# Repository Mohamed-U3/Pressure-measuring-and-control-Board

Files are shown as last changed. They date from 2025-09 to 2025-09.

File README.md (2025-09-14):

# ESP‑12 Pressure Control Circuit

A modular ESP‑12E (ESP8266) hardware design for pressure sensing, load driving, and safe power management with battery charging and automatic source switchover.

<div align="center">
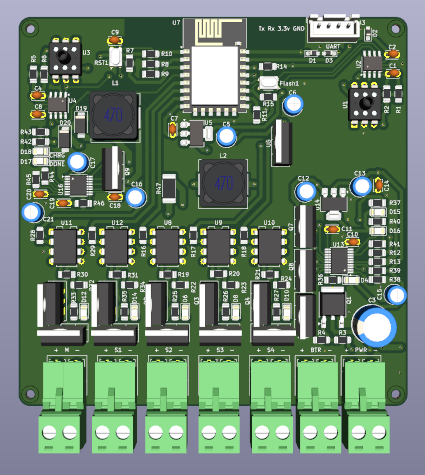
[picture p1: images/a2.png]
  
</div>

<div align="center">
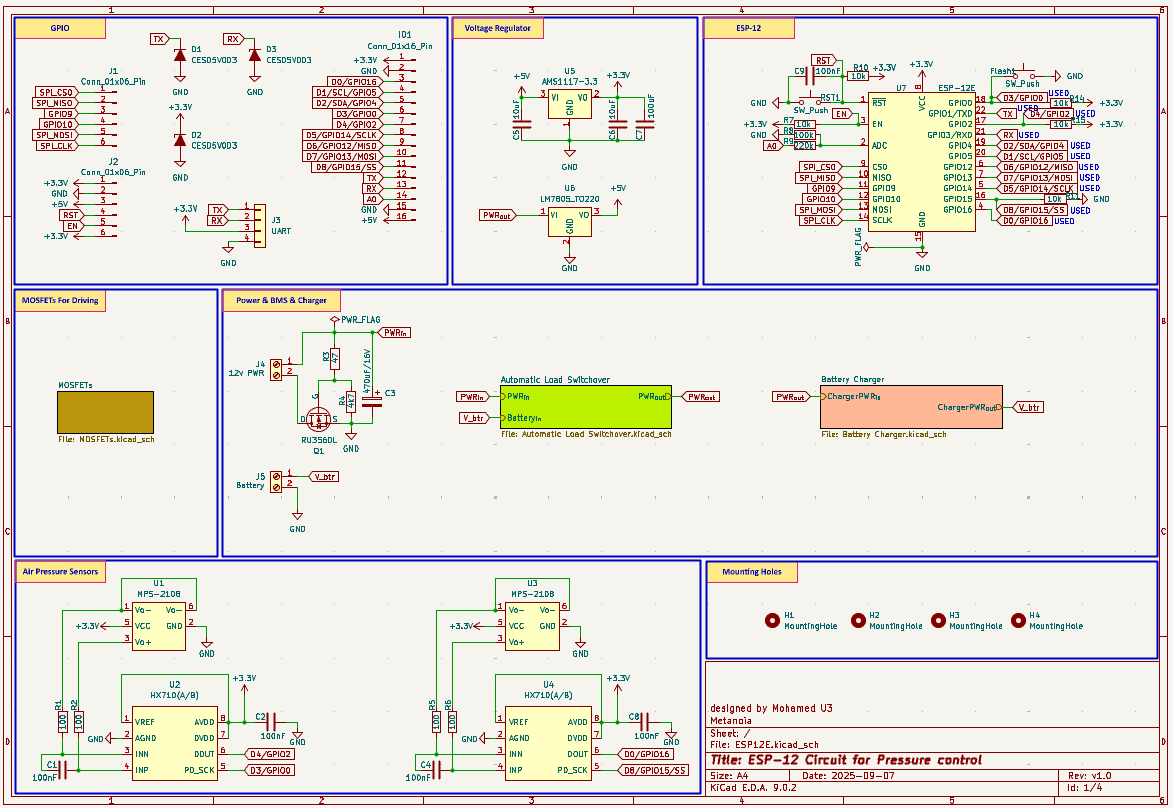
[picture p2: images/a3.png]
  
</div>

## Overview

This repository contains KiCad 9.0.2 schematics for a pressure‑control system built around an ESP‑12E module, dual precision pressure measurement channels, high‑side battery/adapter power path control, and isolated MOSFET drivers for solenoids and a motor.
The design includes an onboard CN3703 Li‑ion charger, AMS1117‑3.3/LM7805 regulators, TLP250 gate drivers, and IRF540N power MOSFETs with Schottky flyback protection, organized across four hierarchical sheets.

## Schematic set

- ESP‑12 top‑level: ESP‑12E module, boot/EN/RST conditioning, ESD protection, sensor ADCs, and header breakout.
- MOSFETs: Four opto‑isolated TLP250 driver channels feeding IRF540N MOSFETs for Sol_1…Sol_4 and Motor outputs with MBR745 freewheel diodes and LED indicators.
- Automatic Load Switchover: LTC2952 power management, dual 2SJ174 P‑MOSFET path control, and local 3.3 V/5 V regulation for state control and status.
- Battery Charger: CN3703 Li‑ion charger with SS36 rectifiers, 22 µH power inductors, 0.1 Ω sense, and charge/done LED indicators.

## Files and structure

- ESP12E.kicad_sch: Top‑level ESP‑12 sheet with sensors, regulators, ESD, UART, and I/O header.
- MOSFETs.kicad_sch: Isolated drivers, MOSFET power stages, connectors for solenoids and motor.
- Automatic Load Switchover.kicad_sch: LTC2952 control, P‑channel power multiplexing, timing/configuration network.
- Battery Charger.kicad_sch: CN3703 charger stage with power path elements and indicators.

## Power architecture

- Input power is provided via a 12 V PWR connector with bulk filtering (e.g., 470 µF/16 V C3) feeding a 5 V LM7805 and a 3.3 V AMS1117 rail, duplicated where needed on control sheets.
- Automatic source switchover uses LTC2952 to supervise ON/OFF timing, power‑fail, watchdog, and gate‑drive outputs for back‑to‑back 2SJ174 P‑MOSFETs controlling PWR_in/PWR_out and Battery_in.
- The CN3703 charger implements Li‑ion charging with SS36 diodes, 22 µH inductors, 0.1 Ω current sense, and CHRG/DONE LED status, feeding the battery power domain.

## Sensing and ADC

- Two HX710(A/B) precision ADC channels interface differential pressure sensors labeled MPS‑2108, each with Vo+/Vo−, VCC, and local decoupling.
- Each ADC section provides AVDD/DVDD partitioning, PD_SCK/DOUT digital lines to the ESP‑12E, and VREF/AGND nodes for stable measurement.

## Microcontroller core

- ESP‑12E (ESP8266) module exposes GPIO0–GPIO16, UART TX/RX, SPI, ADC (A0), EN, and RST, with pull networks for proper boot mode and reset behavior.
- ESD protection diodes (CESD5V0D3) are placed on sensitive I/O and rails including UART, reset, and 3.3 V nodes to improve robustness.

## Isolated drivers and loads

- Four TLP250 opto‑gate drivers provide isolation between the ESP‑12 logic domain and the IRF540N power stages, each with dedicated gate resistors and LED activity indicators.
- Outputs are presented on headers as Sol_1, Sol_2, Sol_3, Sol_4, and Motor, each clamped by MBR745 Schottky diodes for inductive flyback protection.

## Connectors

- J4 12v PWR: main DC input for the regulator stages and system rails.
- J6–J10: load connectors labeled Sol_1…Sol_4 and Motor for external actuators.
- J3 UART: UART header with GND and supply pins for programming and debug.
- J1/J2 headers: general I/O and power breakouts, including +3.3 V, +5 V, and ground.

## Pin breakout (IO1 1×16)

| Pin/Net | Function |
| :--- | :--- |
| +3.3V | 3.3 V rail for peripherals |
| GND | Ground reference |
| D0/GPIO16 | Wake/deep‑sleep capable digital I/O |
| D1/SCL/GPIO5 | I2C SCL or GPIO |
| D2/SDA/GPIO4 | I2C SDA or GPIO |
| D3/GPIO0 | Boot strap/GPIO, used for programming mode |
| D4/GPIO2 | Boot strap/GPIO |
| D5/GPIO14/SCLK | SPI SCLK or GPIO |
| D6/GPIO12/MISO | SPI MISO or GPIO |
| D7/GPIO13/MOSI | SPI MOSI or GPIO |
| D8/GPIO15/SS | Boot strap/SPI SS |
| TX/GPIO1 | UART TXD |
| RX/GPIO3 | UART RXD |
| A0/ADC | Analog input to ESP8266 |
| GND | Ground reference |

## Boot and programming

- EN and RST are broken out with push‑buttons and pull resistors for stable power‑up and manual reset.
- Boot straps on GPIO0/GPIO2/GPIO15 are provisioned via resistor networks to ensure normal boot, with access for entering programming mode via GPIO0.

## Protections and indicators

- Transient suppression uses CESD5V0D3 devices on supply and data lines close to connectors and the ESP‑12E pins.
- Multiple LEDs indicate power presence, driver activity, and charger state (CHRG/DONE), aiding bring‑up and troubleshooting.

## Build notes

- Designed with KiCad E.D.A. 9.0.2; open the top‑level ESP12E.kicad_sch and traverse hierarchical sheets for editing and ERC.
- Validate regulator thermal performance and inductor/diode current ratings for intended solenoid and motor loads before committing to PCB or enclosure.

## Key components

- MCU and IO: ESP‑12E module with 1×16 IO header and a 1×6 programming/UART header.
- Sensing: 2× HX710(A/B) ADCs with MPS‑2108 pressure sensors and precision analog routing.
- Power: LM7805_TO220, AMS1117‑3.3, bulk/tantalum/ceramic decoupling, and LTC2952‑controlled high‑side switching with 2SJ174 P‑MOSFETs.
- Charger: CN3703 with SS36, 22 µH inductors, 0.1 Ω sense, and charge/done LEDs.
- Drivers: TLP250 opto drivers and IRF540N MOSFETs with MBR745 clamps and LED indicators.

## Getting started

- Power the board from the 12 V input or the battery domain once assembled and verified on bench with dummy loads.
- Program the ESP‑12E via the UART header using normal ESP8266 flashing procedure after pulling GPIO0 low for programming mode.

## Safety

- Observe proper isolation, heat sinking, and wiring gauge for motor/solenoid currents, and verify flyback diodes are oriented correctly before first power‑up.
- Double‑check charger and battery polarity, and do not operate unattended during initial charge‑cycle validation.

## Attribution

Metanoia — designed by Mohamed Yousry, Mechatronics/Embedded Hardware Engineer.

## License

This project is licensed under the [MIT License](LICENSE).

## Version

Schematic Rev v1.0, dated 2025‑09‑07.

## What’s included

- Complete multi‑sheet KiCad schematics with hierarchical organization for core MCU, drivers, switchover, and charging.
- Net labels and headers to speed firmware pin mapping for UART, SPI, I2C, and ADC integration on the ESP‑12E.

## Why this design

The project combines reliable power‑path control, isolated high‑current drivers, and precision sensing into a compact ESP8266 platform for pressure‑based automation tasks.

<div style="text-align: center">⁂</div>

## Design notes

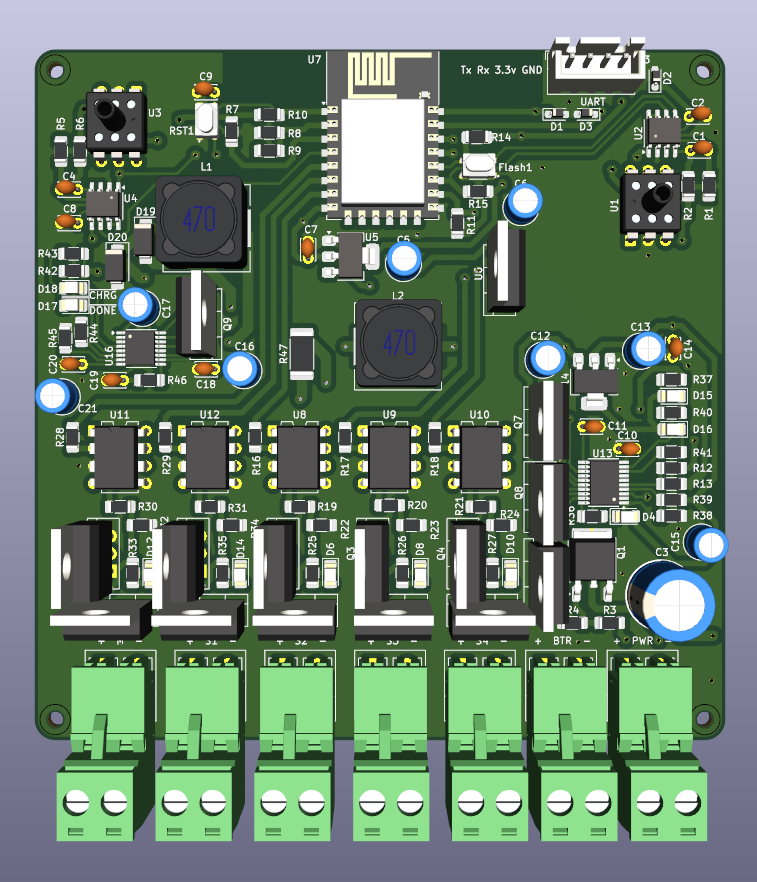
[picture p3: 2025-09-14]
images/a1.png

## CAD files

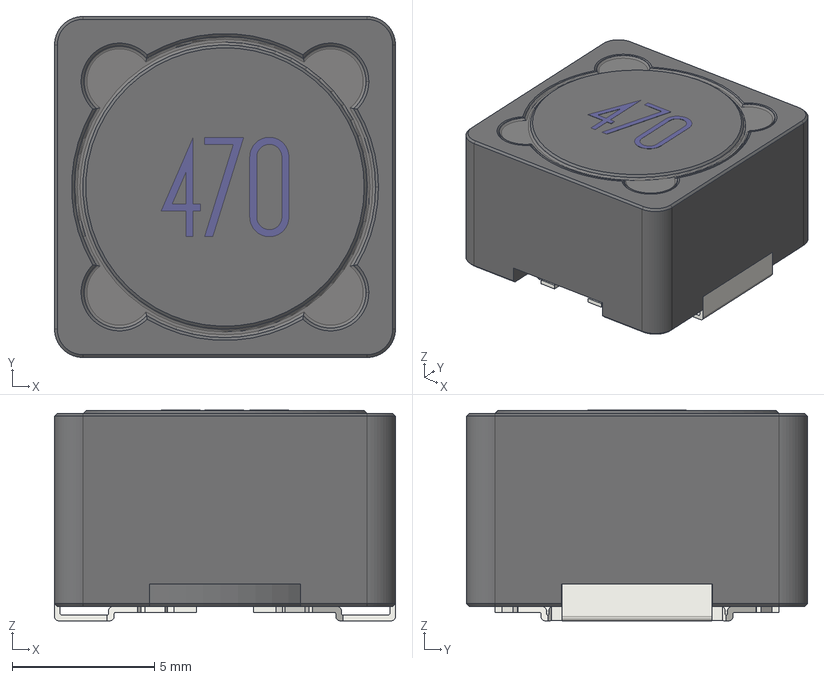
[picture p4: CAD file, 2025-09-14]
3D modules/CDRH127_470M.step
12.0 x 12.0 x 7.41 mm

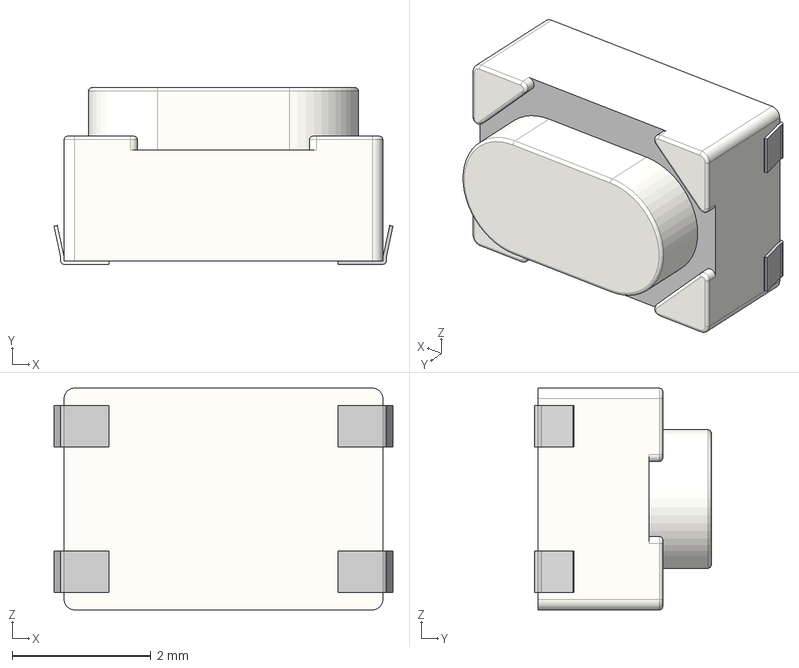
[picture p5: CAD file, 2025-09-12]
3D modules/SKRPACE010 v4.step
4.89 x 2.55 x 3.20 mm

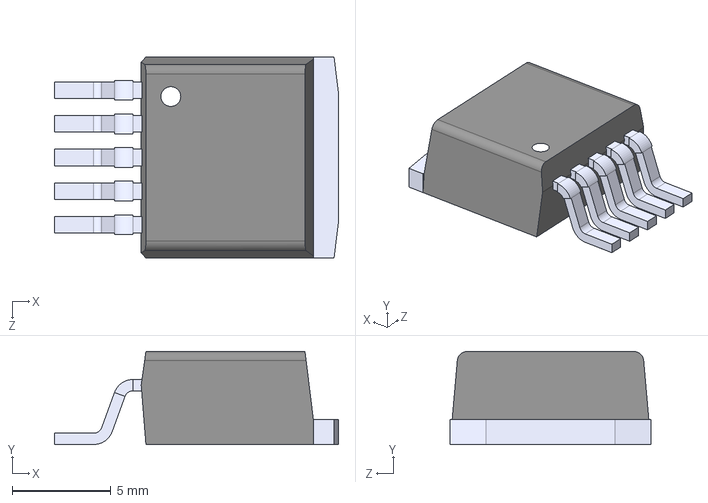
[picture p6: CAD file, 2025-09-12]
3D modules/XL6019E1--3DModel-STEP-510211.STEP
14.4 x 4.70 x 10.2 mm

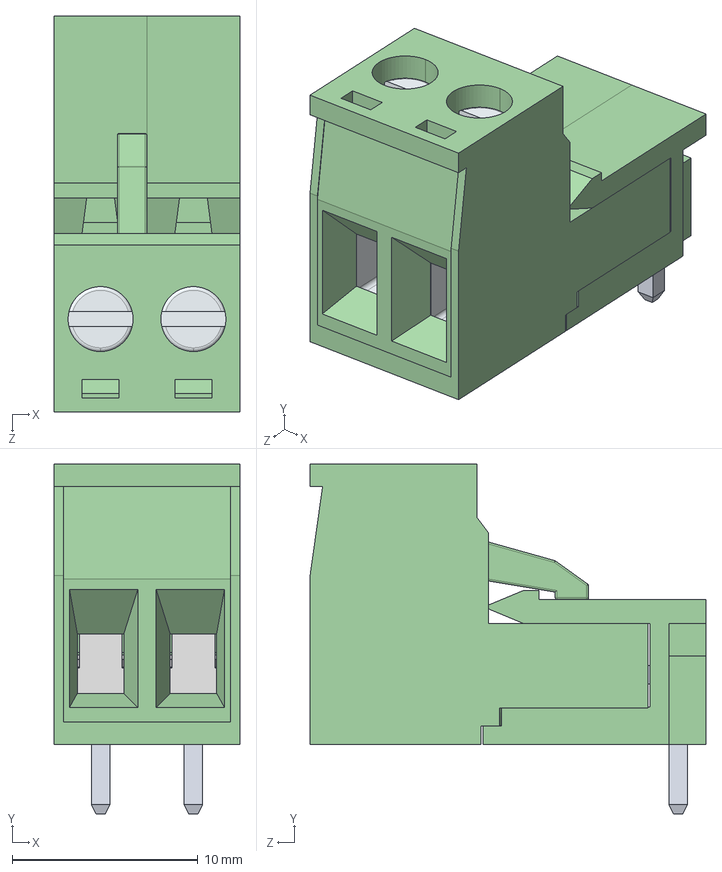
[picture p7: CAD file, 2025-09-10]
3D modules/2P.STEP
10.0 x 18.9 x 21.3 mm
6913527100xx_PIN.stp x 2
6913527100xxCAGE.stp x 2
6913527100xx_VIS.stp x 2
691352710002.stp
691352710002_COFFRE.stp
Metal x 2
Socket x 2

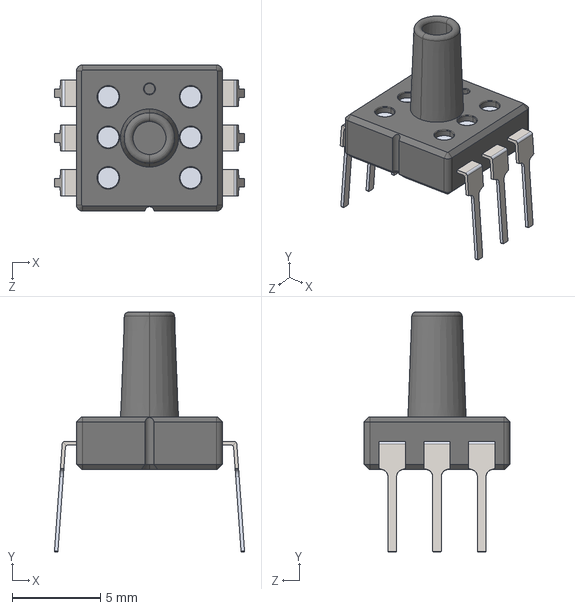
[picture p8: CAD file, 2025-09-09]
3D modules/Air_Pressure_sensor.STEP
10.8 x 13.6 x 8.30 mm

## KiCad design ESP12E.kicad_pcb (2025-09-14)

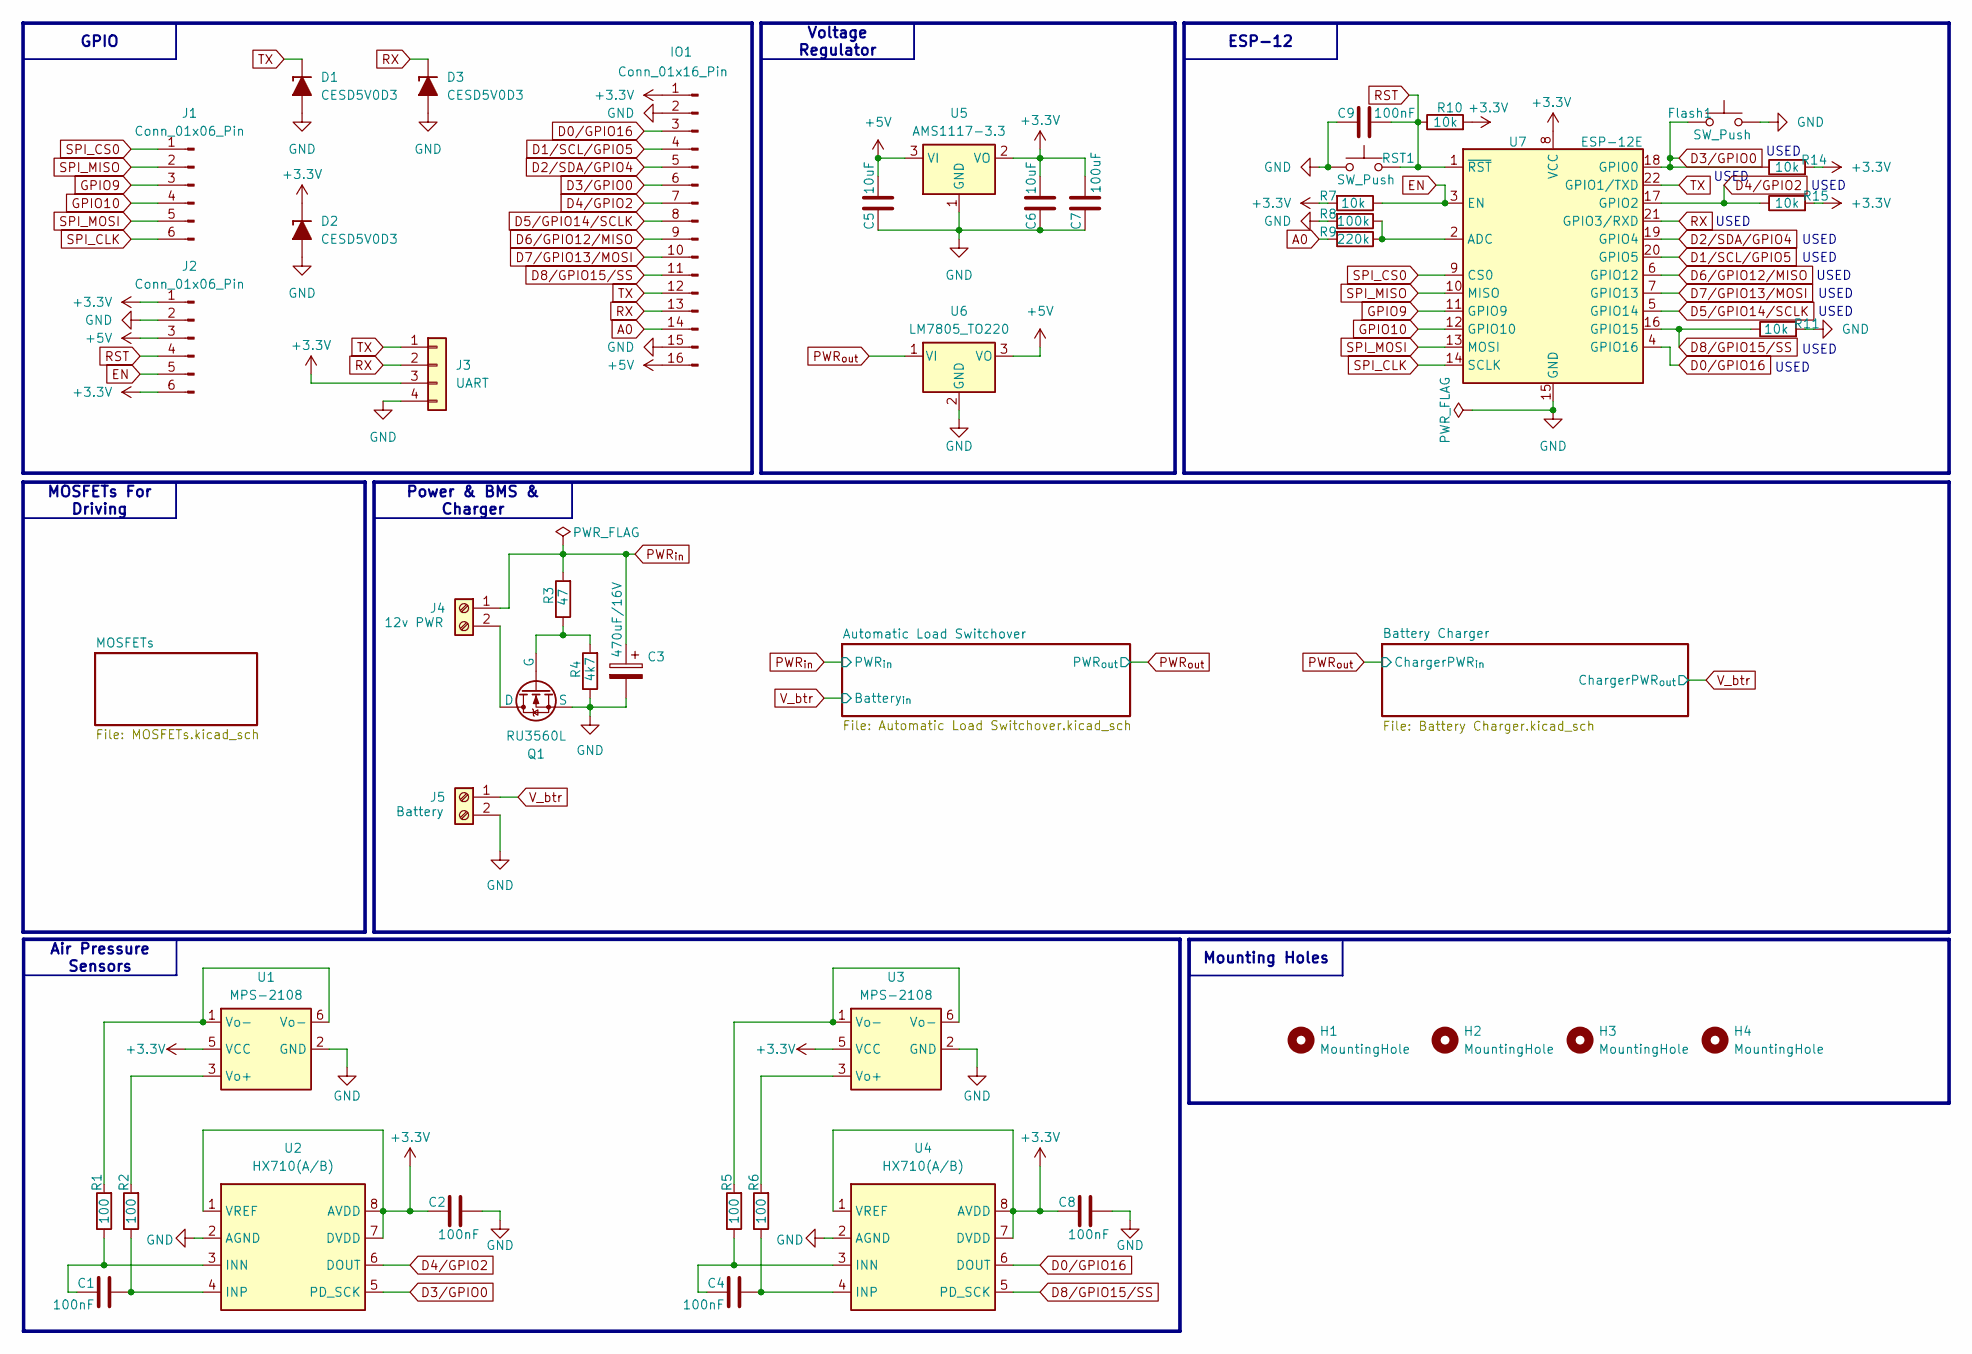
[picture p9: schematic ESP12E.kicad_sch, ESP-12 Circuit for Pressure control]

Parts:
C1, C2, C4, C8, C9: 100nF; C_Disc_D3.0mm_W2.0mm_P2.50mm
C3: 470uF/16V; CP_Radial_D10.0mm_P3.80mm
C5, C6: 10uF; C_Radial_D5.0mm_H5.0mm_P2.00mm
C7: 100uF; C_Disc_D3.0mm_W2.0mm_P2.50mm
D1, D2, D3: CESD5V0D3; D_SOD-323_HandSoldering
Flash1: SW_Push; SW_SKRPACE010
H1, H2, H3, H4: MountingHole; MountingHole_2.2mm_M2
IO1: Conn_01x16_Pin; PinHeader_1x16_P2.54mm_Vertical
J1, J2: Conn_01x06_Pin; PinHeader_1x06_P2.54mm_Vertical
J3: UART; JST_XH_B4B-XH-A_1x04_P2.50mm_Vertical
J4: 12v PWR; TerminalBlock_RND_205-00276_1x02_P5.00mm_Vertical
J5: Battery; TerminalBlock_RND_205-00276_1x02_P5.00mm_Vertical
Q1: RU3560L; TO-252-2
R1, R2, R5, R6: 100; R_1206_3216Metric_Pad1.30x1.75mm_HandSolder
R3: 47; R_1206_3216Metric_Pad1.30x1.75mm_HandSolder
R4: 4k7; R_1206_3216Metric_Pad1.30x1.75mm_HandSolder
R7, R10, R11, R14, R15: 10k; R_1206_3216Metric_Pad1.30x1.75mm_HandSolder
R8: 100k; R_1206_3216Metric_Pad1.30x1.75mm_HandSolder
R9: 220k; R_1206_3216Metric_Pad1.30x1.75mm_HandSolder
RST1: SW_Push; SW_SKRPACE010
U1, U3: MPS-2108; DIP-6_W10.16mm
U2, U4: HX710(A/B); SOP-8_3.9x4.9mm_P1.27mm
U5: AMS1117-3.3; SOT-223-3_TabPin2
U6: LM7805_TO220; TO-220-3_Vertical
U7: ESP-12E

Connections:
+3.3V: C2.1, C6.2, C7.2, C8.1, D2.1 (K), IO1.1, J2.1, J2.6, J3.3, R7.2, R10.2, R14.2, R15.2, U1.5 (VCC), U2.1 (VREF), U2.7 (DVDD), U2.8 (AVDD), U3.5 (VCC), U4.1 (VREF), U4.7 (DVDD), U4.8 (AVDD), U5.2 (VO), U7.8 (VCC)
+5V: C5.2, IO1.16, J2.3, U5.3 (VI), U6.3 (VO)
A0: IO1.14, R9.2
D0/GPIO16: IO1.3, U4.6 (DOUT), U7.4 (GPIO16)
D1/SCL/GPIO5: IO1.4, U7.20 (GPIO5); also elsewhere on the board
D2/SDA/GPIO4: IO1.5, U7.19 (GPIO4); also elsewhere on the board
D3/GPIO0: Flash1.2, IO1.6, R14.1, U2.5 (PD_SCK), U7.18 (GPIO0)
D4/GPIO2: IO1.7, R15.1, U2.6 (DOUT), U7.17 (GPIO2)
D5/GPIO14/SCLK: IO1.8, U7.5 (GPIO14); also elsewhere on the board
D6/GPIO12/MISO: IO1.9, U7.6 (GPIO12); also elsewhere on the board
D7/GPIO13/MOSI: IO1.10, U7.7 (GPIO13); also elsewhere on the board
D8/GPIO15/SS: IO1.11, R11.1, U4.5 (PD_SCK), U7.16 (GPIO15)
EN: J2.5, R7.1, U7.3 (EN)
GND: C2.2, C3.2, C5.1, C6.1, C7.1, C8.2, C9.1, D1.2 (A), D2.2 (A), D3.2 (A), Flash1.1, IO1.2, IO1.15, J2.2, J3.4, J5.2, Q1.3 (S), R4.1, R8.2, R11.2, RST1.1, U1.2 (GND), U2.2 (AGND), U3.2 (GND), U4.2 (AGND), U5.1 (GND), U6.2 (GND), U7.15 (GND); also elsewhere on the board
GPIO9: J1.3, U7.11 (GPIO9)
GPIO10: J1.4, U7.12 (GPIO10)
unnamed: J4.2, Q1.2 (D)
unnamed: Q1.1 (G), R3.1, R4.2
unnamed: R1.2, U1.1 (Vo-), U1.6 (Vo-)
unnamed: R5.2, U3.1 (Vo-), U3.6 (Vo-)
unnamed: R2.2, U1.3 (Vo+)
unnamed: C1.1, R1.1, U2.3 (INN)
unnamed: C1.2, R2.1, U2.4 (INP)
unnamed: R6.2, U3.3 (Vo+)
unnamed: C4.1, R5.1, U4.3 (INN)
unnamed: C4.2, R6.1, U4.4 (INP)
unnamed: R8.1, R9.1, U7.2 (ADC)
PWR_{in}: C3.1, J4.1, R3.2; also elsewhere on the board
PWR_{out}: U6.1 (VI); also elsewhere on the board
RST: C9.2, J2.4, R10.1, RST1.2, U7.1 (~RST)
RX: D3.1 (K), IO1.13, J3.2, U7.21 (GPIO3/RXD)
SPI_CLK: J1.6, U7.14 (SCLK)
SPI_CS0: J1.1, U7.9 (CS0)
SPI_MISO: J1.2, U7.10 (MISO)
SPI_MOSI: J1.5, U7.13 (MOSI)
TX: D1.1 (K), IO1.12, J3.1, U7.22 (GPIO1/TXD)
V_btr: J5.1; also elsewhere on the board

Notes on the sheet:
USED
MOSFETs For Driving
ESP-12
Power & BMS & Charger
GPIO
Voltage Regulator
Air Pressure Sensors
Mounting Holes

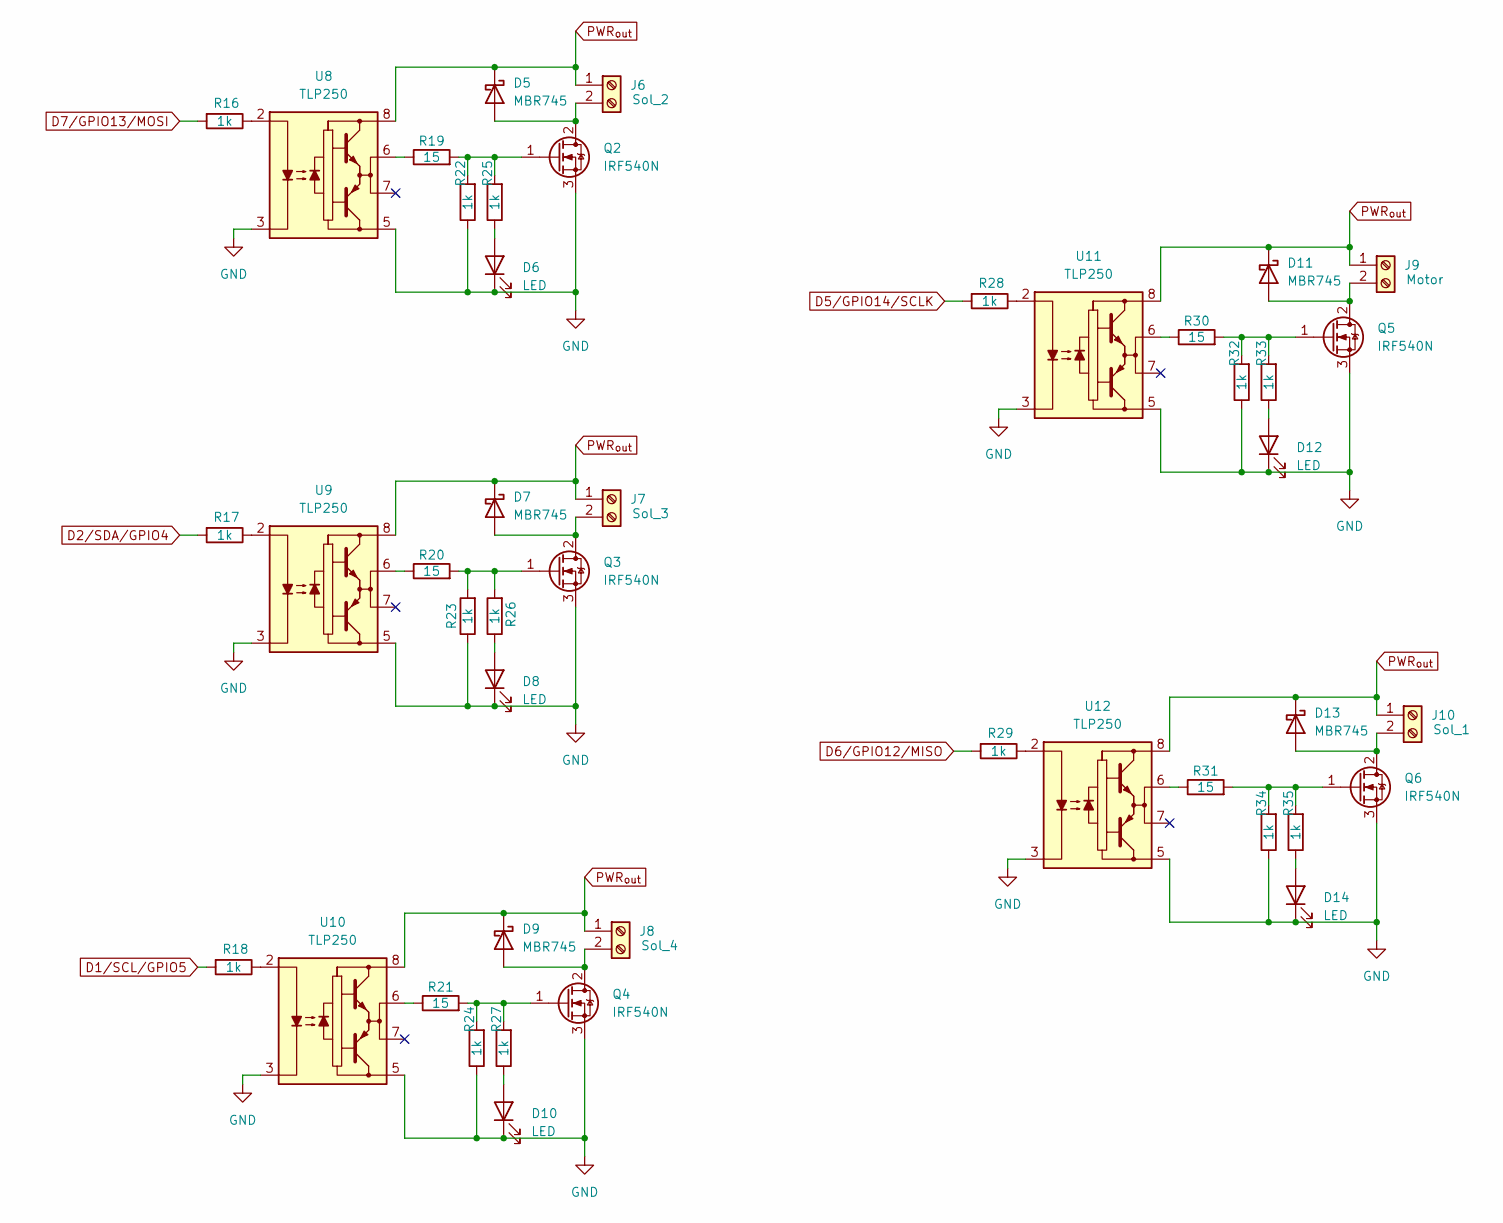
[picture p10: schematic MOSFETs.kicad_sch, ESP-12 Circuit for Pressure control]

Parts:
D5, D7, D9, D11, D13: MBR745; TO-220-2_Vertical
D6, D8, D10, D12, D14: LED; LED_1206_3216Metric
J6: Sol_2; TerminalBlock_RND_205-00276_1x02_P5.00mm_Vertical
J7: Sol_3; TerminalBlock_RND_205-00276_1x02_P5.00mm_Vertical
J8: Sol_4; TerminalBlock_RND_205-00276_1x02_P5.00mm_Vertical
J9: Motor; TerminalBlock_RND_205-00276_1x02_P5.00mm_Vertical
J10: Sol_1; TerminalBlock_RND_205-00276_1x02_P5.00mm_Vertical
Q2, Q3, Q4, Q5, Q6: IRF540N; TO-220-3_Vertical
R16, R17, R18, R22, R23, R24, R25, R26, R27, R28, R29, R32, R33, R34, R35: 1k; R_1206_3216Metric_Pad1.30x1.75mm_HandSolder
R19, R20, R21, R30, R31: 15; R_1206_3216Metric_Pad1.30x1.75mm_HandSolder
U8, U9, U10, U11, U12: TLP250; DIP-8_W7.62mm

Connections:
D1/SCL/GPIO5: R18.2; also elsewhere on the board
D2/SDA/GPIO4: R17.2; also elsewhere on the board
D5/GPIO14/SCLK: R28.2; also elsewhere on the board
D6/GPIO12/MISO: R29.2; also elsewhere on the board
D7/GPIO13/MOSI: R16.2; also elsewhere on the board
GND: D6.1 (K), D8.1 (K), D10.1 (K), D12.1 (K), D14.1 (K), Q2.3 (S), Q3.3 (S), Q4.3 (S), Q5.3 (S), Q6.3 (S), R22.1, R23.1, R24.1, R32.1, R34.1, U8.3 (C), U8.5 (VEE), U9.3 (C), U9.5 (VEE), U10.3 (C), U10.5 (VEE), U11.3 (C), U11.5 (VEE), U12.3 (C), U12.5 (VEE); also elsewhere on the board
unnamed: D5.2 (A), J6.2, Q2.2 (D)
unnamed: D6.2 (A), R25.1
unnamed: D7.2 (A), J7.2, Q3.2 (D)
unnamed: D8.2 (A), R26.1
unnamed: D9.2 (A), J8.2, Q4.2 (D)
unnamed: D10.2 (A), R27.1
unnamed: D11.2 (A), J9.2, Q5.2 (D)
unnamed: D12.2 (A), R33.1
unnamed: D13.2 (A), J10.2, Q6.2 (D)
unnamed: D14.2 (A), R35.1
unnamed: Q2.1 (G), R19.2, R22.2, R25.2
unnamed: Q3.1 (G), R20.2, R23.2, R26.2
unnamed: Q4.1 (G), R21.2, R24.2, R27.2
unnamed: Q5.1 (G), R30.2, R32.2, R33.2
unnamed: Q6.1 (G), R31.2, R34.2, R35.2
unnamed: R19.1, U8.6 (VO)
unnamed: R20.1, U9.6 (VO)
unnamed: R21.1, U10.6 (VO)
unnamed: R30.1, U11.6 (VO)
unnamed: R31.1, U12.6 (VO)
unnamed: R16.1, U8.2 (A)
unnamed: R17.1, U9.2 (A)
unnamed: R18.1, U10.2 (A)
unnamed: R28.1, U11.2 (A)
unnamed: R29.1, U12.2 (A)
PWR_{out}: D5.1 (K), D7.1 (K), D9.1 (K), D11.1 (K), D13.1 (K), J6.1, J7.1, J8.1, J9.1, J10.1, U8.8 (VCC), U9.8 (VCC), U10.8 (VCC), U11.8 (VCC), U12.8 (VCC); also elsewhere on the board

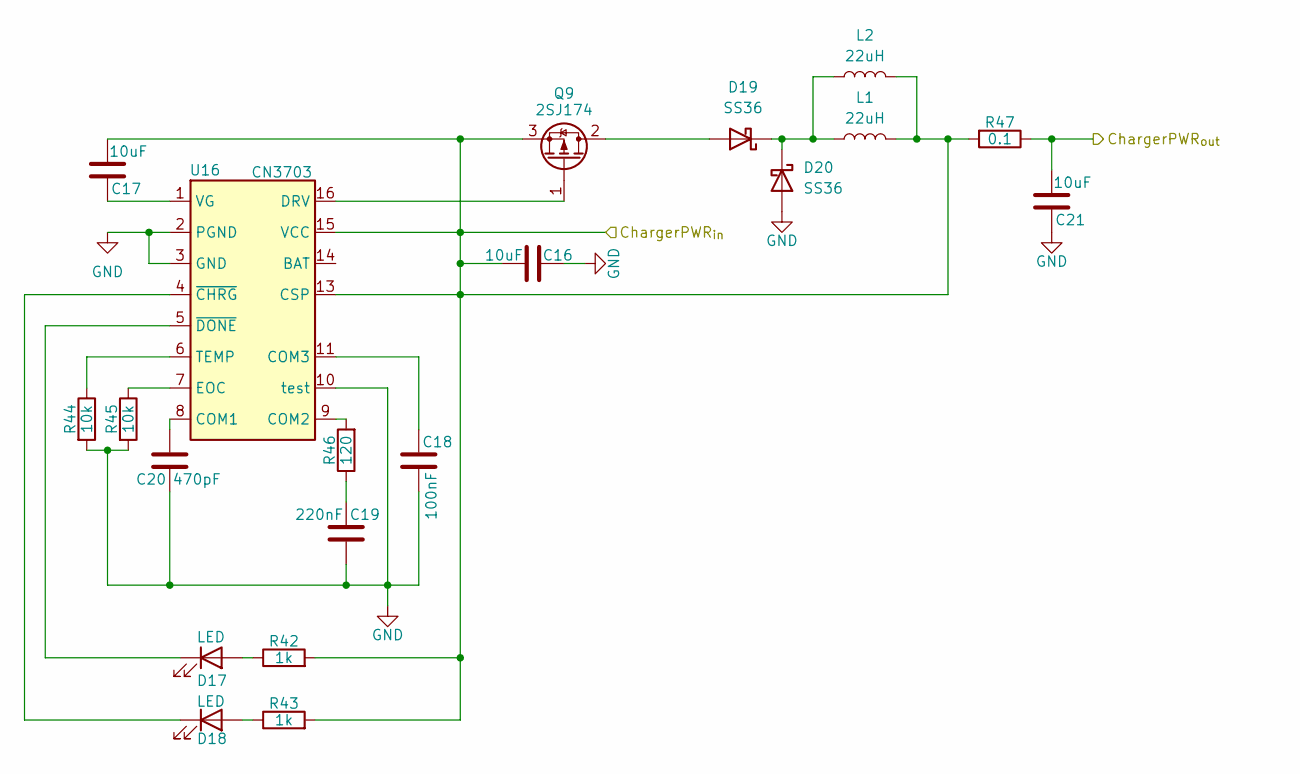
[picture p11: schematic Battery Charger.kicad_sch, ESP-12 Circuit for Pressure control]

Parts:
C16, C17, C21: 10uF; C_Radial_D5.0mm_H5.0mm_P2.00mm
C18: 100nF; C_Disc_D3.0mm_W2.0mm_P2.50mm
C19: 220nF; C_Disc_D3.0mm_W2.0mm_P2.50mm
C20: 470pF; C_Disc_D3.0mm_W2.0mm_P2.50mm
D17, D18: LED; LED_1206_3216Metric
D19, D20: SS36; D_SMA
L1, L2: 22uH; L_12x12mm_H4.5mm
Q9: 2SJ174; TO-220-3_Vertical
R42, R43: 1k; R_1206_3216Metric_Pad1.30x1.75mm_HandSolder
R44, R45: 10k; R_1206_3216Metric_Pad1.30x1.75mm_HandSolder
R46: 120; R_1206_3216Metric_Pad1.30x1.75mm_HandSolder
R47: 0.1; R_2512_6332Metric_Pad1.40x3.35mm_HandSolder
U16: CN3703; TSSOP-16_4.4x5mm_P0.65mm

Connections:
GND: C16.1, C18.1, C19.1, C20.1, C21.1, D20.2 (A), R44.2, R45.2, U16.2 (PGND), U16.3 (GND), U16.10 (test); also elsewhere on the board
unnamed: C19.2, R46.1
unnamed: D17.2 (A), R42.1
unnamed: D17.1 (K), U16.5 (~DONE)
unnamed: D18.2 (A), R43.1
unnamed: D18.1 (K), U16.4 (~CHRG)
unnamed: D19.2 (A), Q9.2 (D)
unnamed: D19.1 (K), D20.1 (K), L1.1, L2.1
unnamed: Q9.1 (G), U16.16 (DRV)
unnamed: C20.2, U16.8 (COM1)
unnamed: R46.2, U16.9 (COM2)
unnamed: C18.2, U16.11 (COM3)
unnamed: R45.1, U16.7 (EOC)
unnamed: R44.1, U16.6 (TEMP)
unnamed: C17.1, U16.1 (VG)
PWR_{out}: C16.2, C17.2, L1.2, L2.2, Q9.3 (S), R42.2, R43.2, R47.2, U16.13 (CSP), U16.15 (VCC); also elsewhere on the board
V_btr: C21.2, R47.1; also elsewhere on the board

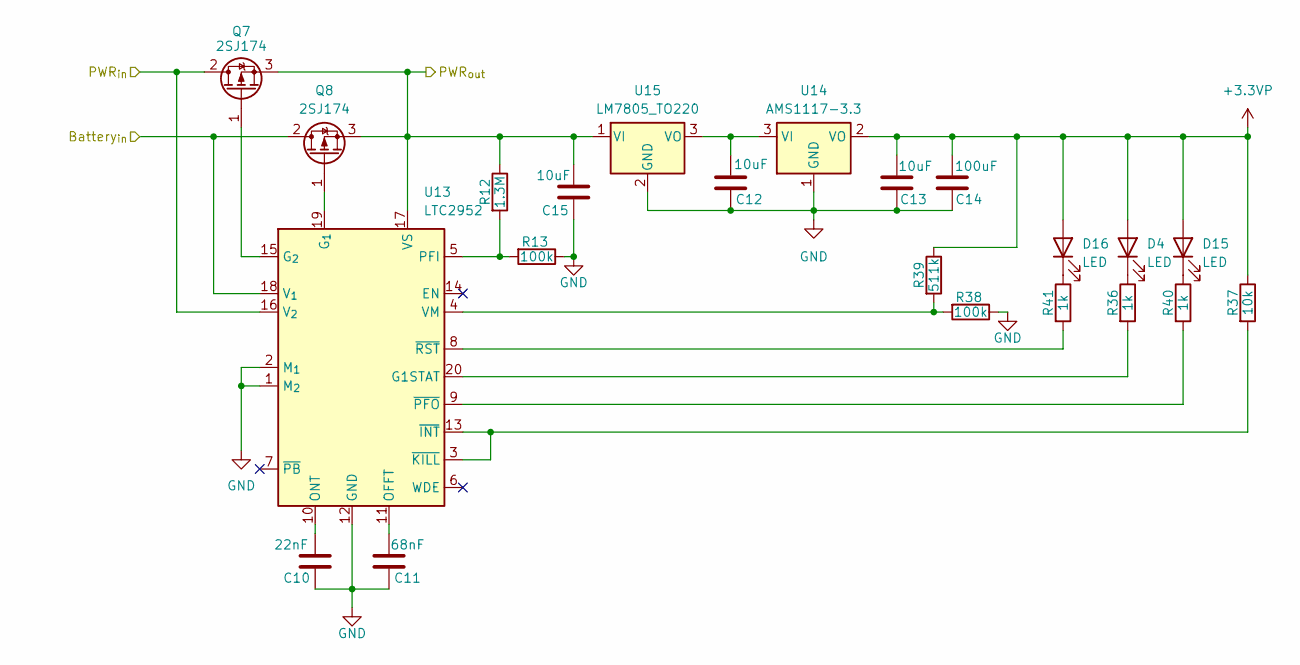
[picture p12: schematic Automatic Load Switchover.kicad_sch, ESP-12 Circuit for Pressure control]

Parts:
C10: 22nF; C_Disc_D3.0mm_W2.0mm_P2.50mm
C11: 68nF; C_Disc_D3.0mm_W2.0mm_P2.50mm
C12, C13, C15: 10uF; C_Radial_D5.0mm_H5.0mm_P2.00mm
C14: 100uF; C_Disc_D3.0mm_W2.0mm_P2.50mm
D4, D15, D16: LED; LED_1206_3216Metric
Q7, Q8: 2SJ174; TO-220-3_Vertical
R12: 1.3M; R_1206_3216Metric_Pad1.30x1.75mm_HandSolder
R13, R38: 100k; R_1206_3216Metric_Pad1.30x1.75mm_HandSolder
R36, R40, R41: 1k; R_1206_3216Metric_Pad1.30x1.75mm_HandSolder
R37: 10k; R_1206_3216Metric_Pad1.30x1.75mm_HandSolder
R39: 511k; R_1206_3216Metric_Pad1.30x1.75mm_HandSolder
U13: LTC2952; ETSSOP-20-1EP_4.4x6.5mm_P0.65mm_EP3x4.2mm
U14: AMS1117-3.3; SOT-223-3_TabPin2
U15: LM7805_TO220; TO-220-3_Vertical

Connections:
+3.3VP: C13.2, C14.2, D4.2 (A), D15.2 (A), D16.2 (A), R37.1, R39.1, U14.2 (VO)
GND: C10.1, C11.1, C12.1, C13.1, C14.1, C15.1, R13.1, R38.1, U13.1 (M_{2}), U13.2 (M_{1}), U13.12 (GND), U14.1 (GND), U15.2 (GND); also elsewhere on the board
unnamed: D4.1 (K), R36.1
unnamed: D15.1 (K), R40.1
unnamed: D16.1 (K), R41.1
unnamed: Q7.1 (G), U13.15 (G_{2})
unnamed: Q8.1 (G), U13.19 (G_{1})
unnamed: R36.2, U13.20 (G1STAT)
unnamed: C11.2, U13.11 (OFFT)
unnamed: C10.2, U13.10 (ONT)
unnamed: R12.2, R13.2, U13.5 (PFI)
unnamed: R38.2, R39.2, U13.4 (VM)
unnamed: R37.2, U13.3 (~KILL), U13.13 (~INT)
unnamed: R40.2, U13.9 (~PFO)
unnamed: R41.2, U13.8 (~RST)
unnamed: C12.2, U14.3 (VI), U15.3 (VO)
PWR_{in}: Q7.2 (D), U13.16 (V_{2}); also elsewhere on the board
PWR_{out}: C15.2, Q7.3 (S), Q8.3 (S), R12.1, U13.17 (VS), U15.1 (VI); also elsewhere on the board
V_btr: Q8.2 (D), U13.18 (V_{1}); also elsewhere on the board

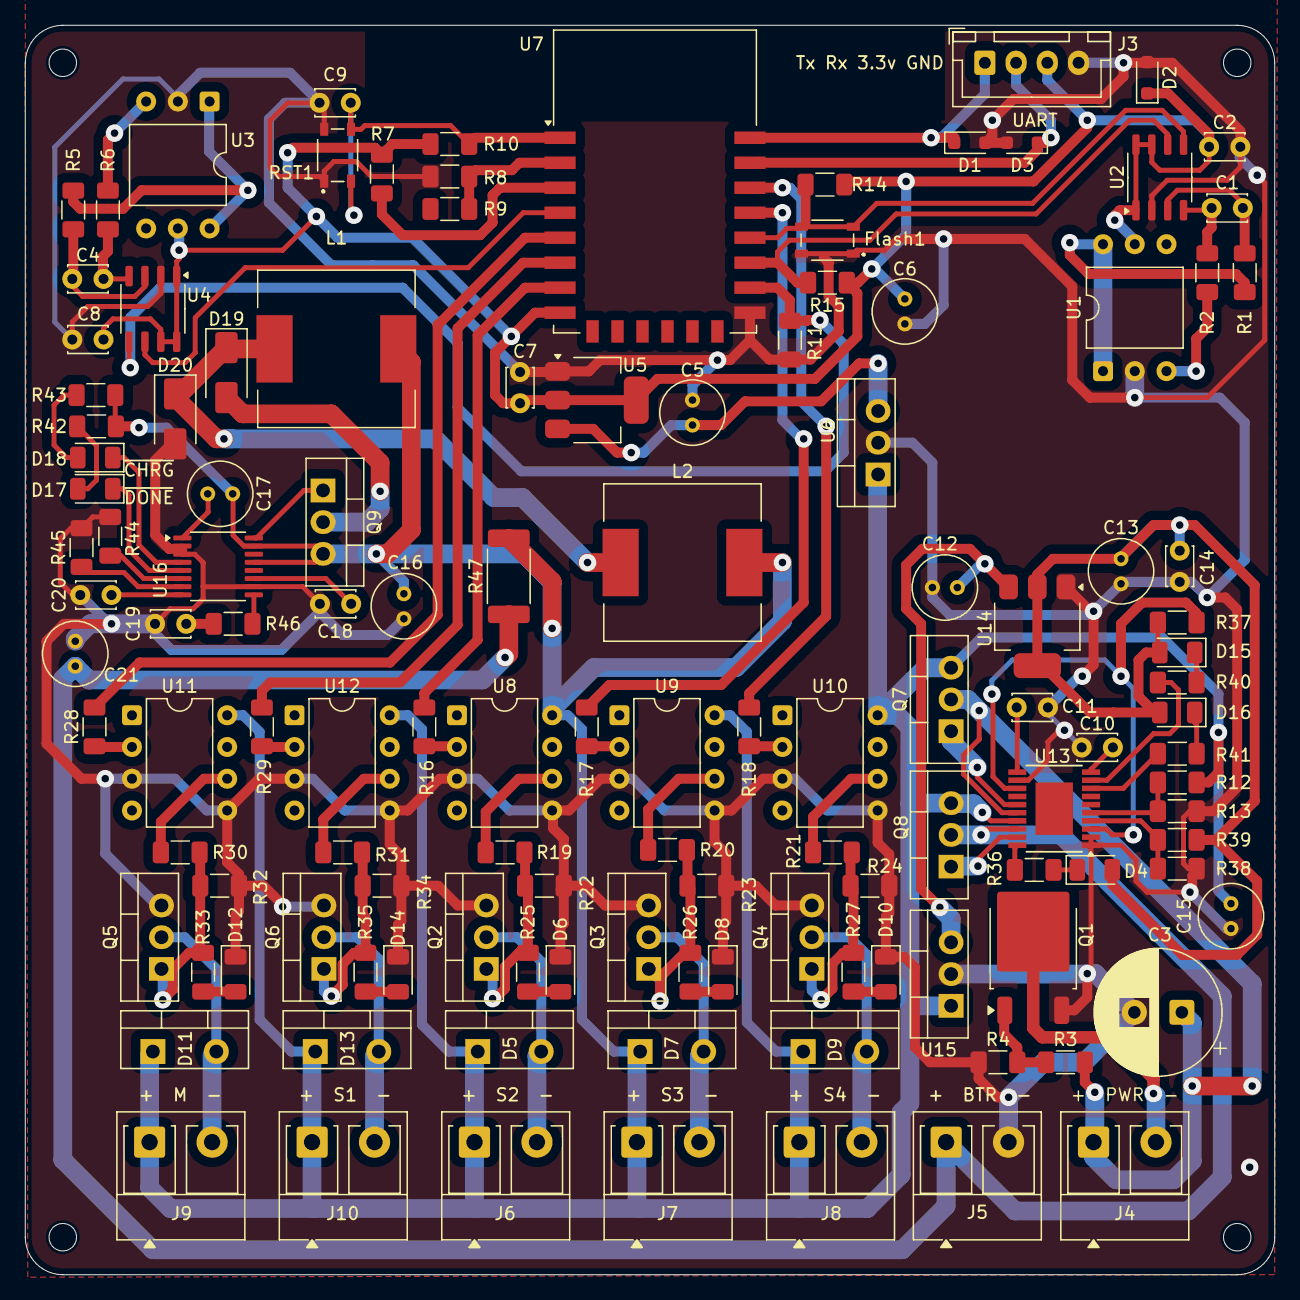
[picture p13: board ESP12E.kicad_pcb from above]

Board: 2 copper layers, 100.0 x 100.0 mm, 129 parts (0 on the bottom side), 84 nets.

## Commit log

2025-09-07 First commit: this is a template for ESP-12 that is gonna be modified for the requirements.
    [ESP12E.kicad_pcb, ESP12E.kicad_sch]
2025-09-07 Feat: adding IRF520 mosfets for controlling Motor of air pump and 4 solinoids.
    [ESP12E.kicad_pcb, ESP12E.kicad_sch]
2025-09-08 feat: pcb is ok now, next Pressure sensor.
    [ESP12E.kicad_pcb, ESP12E.kicad_sch]
2025-09-09 Working: on adding air pressure sensors (MPS-2108).
    [Air_Pressure_sensor.STEP, ESP12E.kicad_pcb, ESP12E.kicad_sch]
2025-09-09 feat: the pressure sensor and some protections (flyback diode) is added.
    [ESP12E.kicad_pcb, ESP12E.kicad_sch]
2025-09-10 Feat: adding TLP250 for Isolation and driving MOSFETs.
    [ESP12E.kicad_pcb, ESP12E.kicad_sch, MOSFETs.kicad_sch]
2025-09-10 working: continue at Work.
    [2P.STEP, 2P.stp, ESP12E.kicad_pcb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]
2025-09-12 Feat: adding Buck converter + making BOM files HTML with LINKs of stores + small edits + adding polarity protection.
    [2P.stp, ESP12E.kicad_pcb, ESP12E.kicad_sch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]
2025-09-12 Fix: edit pcb for manufacturing Bad process (local manufacturing).
    [ESP12E.kicad_pcb]
2025-09-13 Feat: the board now has a circuit that manage the switch between Battery and Adaptor Power.
    [Automatic Load Switchover.kicad_sch, Battery Charger.kicad_sch, ESP12E.kicad_pcb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]
2025-09-14 feat: Battery charging Circuit is added.
    [Battery Charger.kicad_sch, CDRH127_470M.step, ESP12E.kicad_pcb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]
2025-09-14 Final: small edit on silkscreen + BOM file + generating Gerber file.
    [Automatic Load Switchover.kicad_sch, Battery Charger.kicad_sch, ESP12E.kicad_pcb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]
2025-09-20 fix: more Via for better soldering on local production PCB.
